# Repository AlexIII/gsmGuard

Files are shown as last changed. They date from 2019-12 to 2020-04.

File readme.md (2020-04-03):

# GsmGuard
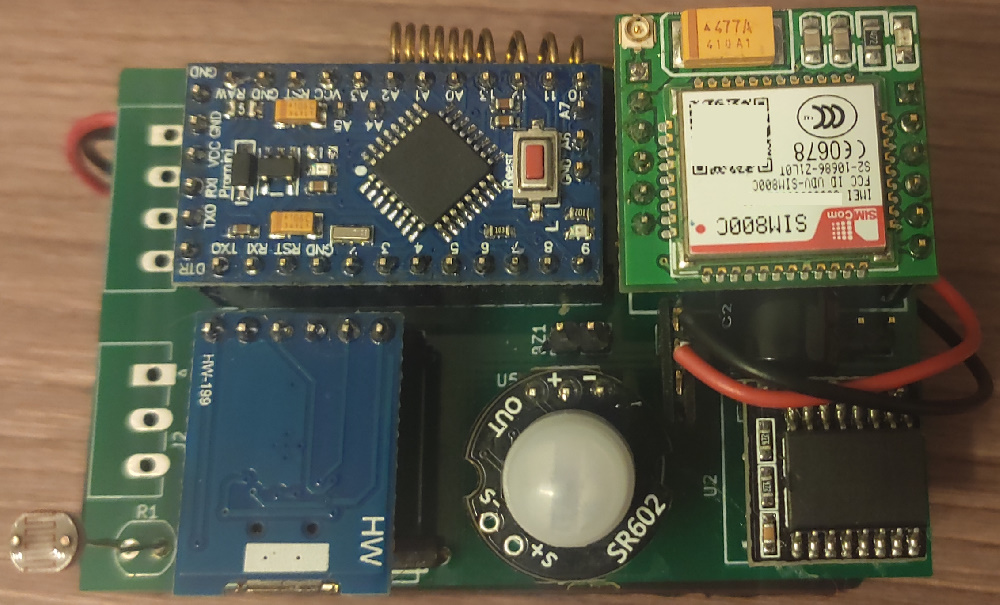
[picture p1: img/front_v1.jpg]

A compact multi-purpose all-in-one open source GSM alarm system.
Build on the base of Arduino Pro Mini and Arduino-compatible modules.

## Features
### Communication
The device sends an SMS on any alarm event and optionally a status report once a day.
Why SMS and not internet service? SMS stays most reliable means of mobile communication in cases of poor signal quality, requires less energy and works directly without relying on central server (which needs to be maintained by someone and may present a security  problem).

Example of an alarm SMS:
```
04.11.19 22:37
Movement detected
```
Example of a daily report SMS:
```
door: Closed [04.11.19 09:14] <-- date and time of last door open event
move: None [04.11.19 09:12] <-- date and time of last movement detection event
temp.: 28*C [min. 21*C, max. 28*C, mean 27*C] <-- current temperature and temperature statistics for the current day
light: 99% <-- current illumination level (0 to 100%)
bat.: 4.6v <-- current battery voltage
ext.1: 0 <-- current state of external sensor 1
ext.2: 0 <-- current state of external sensor 2
```

For every alarm event you can also enable a call to your phone or/and sound alarm.

### Sensors

- Door open sensor (magnetic reed switch)
- Illumination level sensor (photoresistor)
- Motion sensor (PIR sensor)
- Temperature sensor (built-in DS3231)

### Alarm events
- Open door
- Rapid illumination change
- Motion detection
- Too high or too low temperature
- Low battery voltage

### Power supply
Three AA batteries. Expected lifetime: 3 to 6 months.

### Configuration and logging
The device can be connected to a PC via USB for configuration.
Configuration program lets you set target phone number, time of daily SMS report, choose events that will be reported, a way of notification (SMS, call, sound alarm) and set time periods during which those events are being monitored. I.e. if you know that the room is being used during some hours in certain days of the week, you can disable the alarm for that period.
It also shows the last 70 events with date and time and a temperature plot for the last 31 days (one measurement every 2 hours).

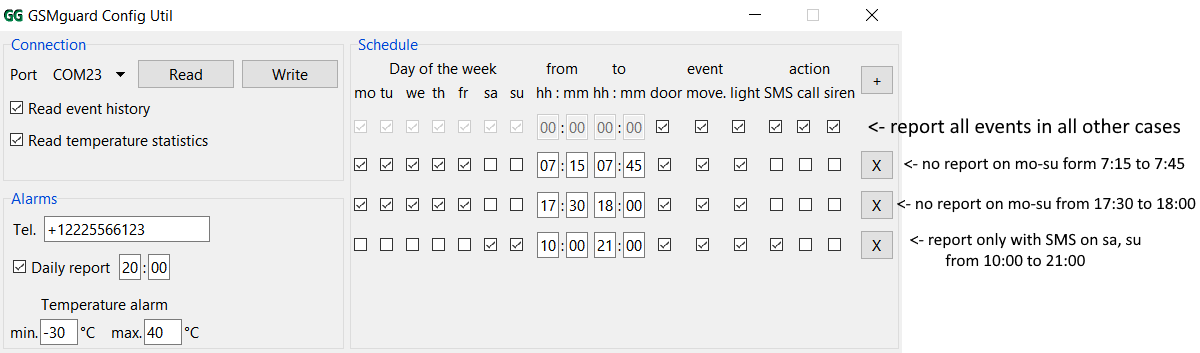
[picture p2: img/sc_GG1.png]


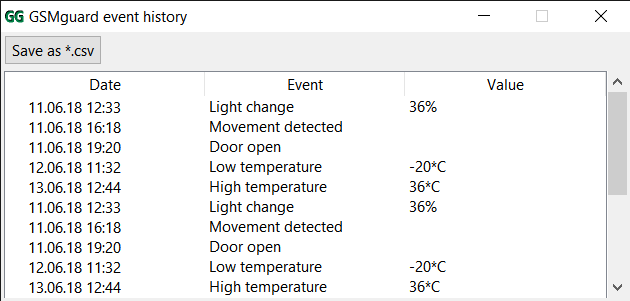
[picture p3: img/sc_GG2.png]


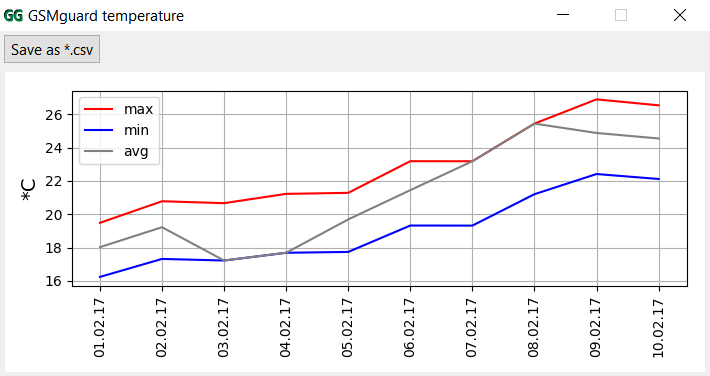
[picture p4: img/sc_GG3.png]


### Localization

Currently supported languages (SMS and configuration program for PC): English, Russian.

Date format: dd/mm/yy

Temperature units: degrees Celsius

## Assembling guide
### Hardware
#### List of components

List of Arduino modules you will need:

- Arduino Pro Mini 3.3v 8MHz (5v 16MHz is also acceptable, but requires different firmware) 

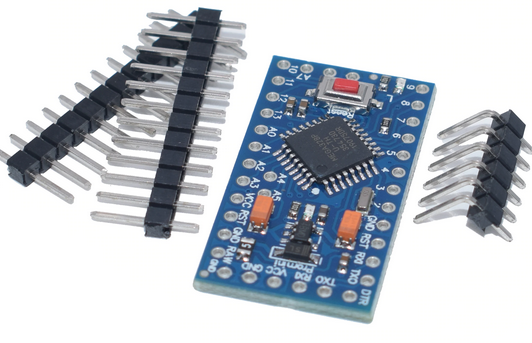
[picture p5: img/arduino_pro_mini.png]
  

-  MH-SR602 MINI Motion Sensor 

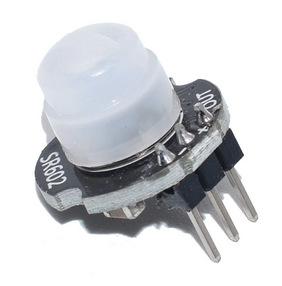
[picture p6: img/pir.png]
  

-  SIM800C GSM Module

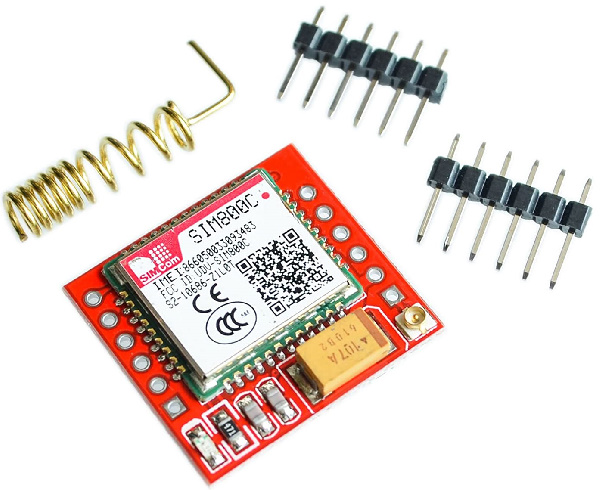
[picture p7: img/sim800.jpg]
  

-  CP2102 MICRO USB to UART TTL Module

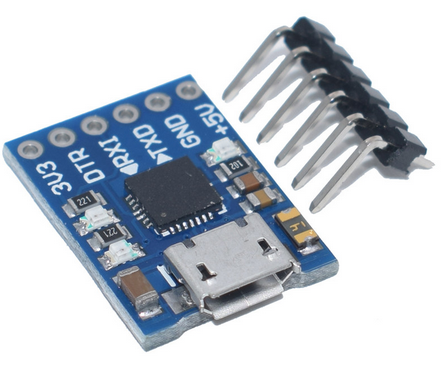
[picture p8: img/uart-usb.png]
  

-  DS3231 RTC Module For Raspberry Pi 

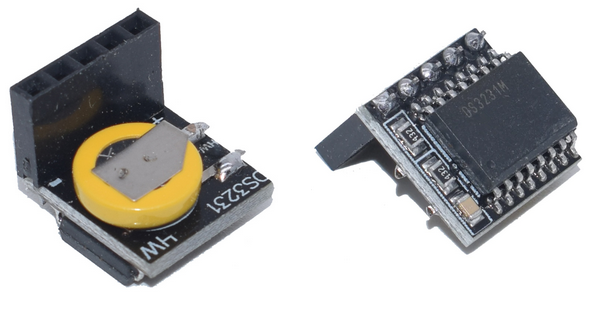
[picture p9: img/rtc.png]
  

Other components

- any >0.5A logic-level P-channel MOSFET in SOT-23

- reed switch

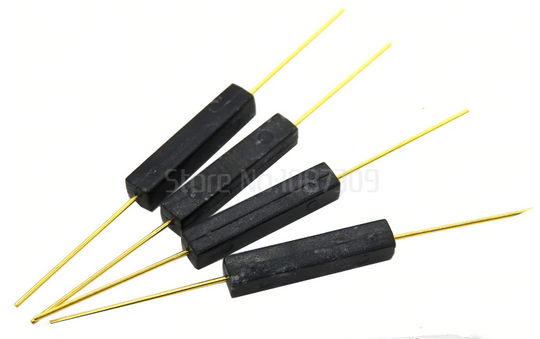
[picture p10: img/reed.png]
  

- buzzer 3 to 5v

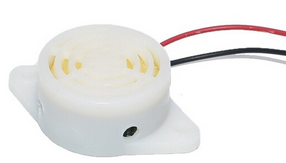
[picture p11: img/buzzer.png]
  

- electret microphone

- photoresistor

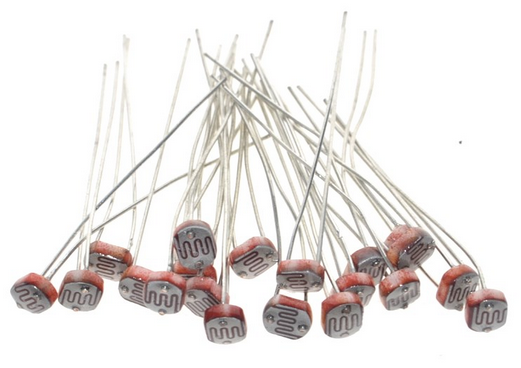
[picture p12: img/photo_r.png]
  

- resistors, capacitors 

The schematics:

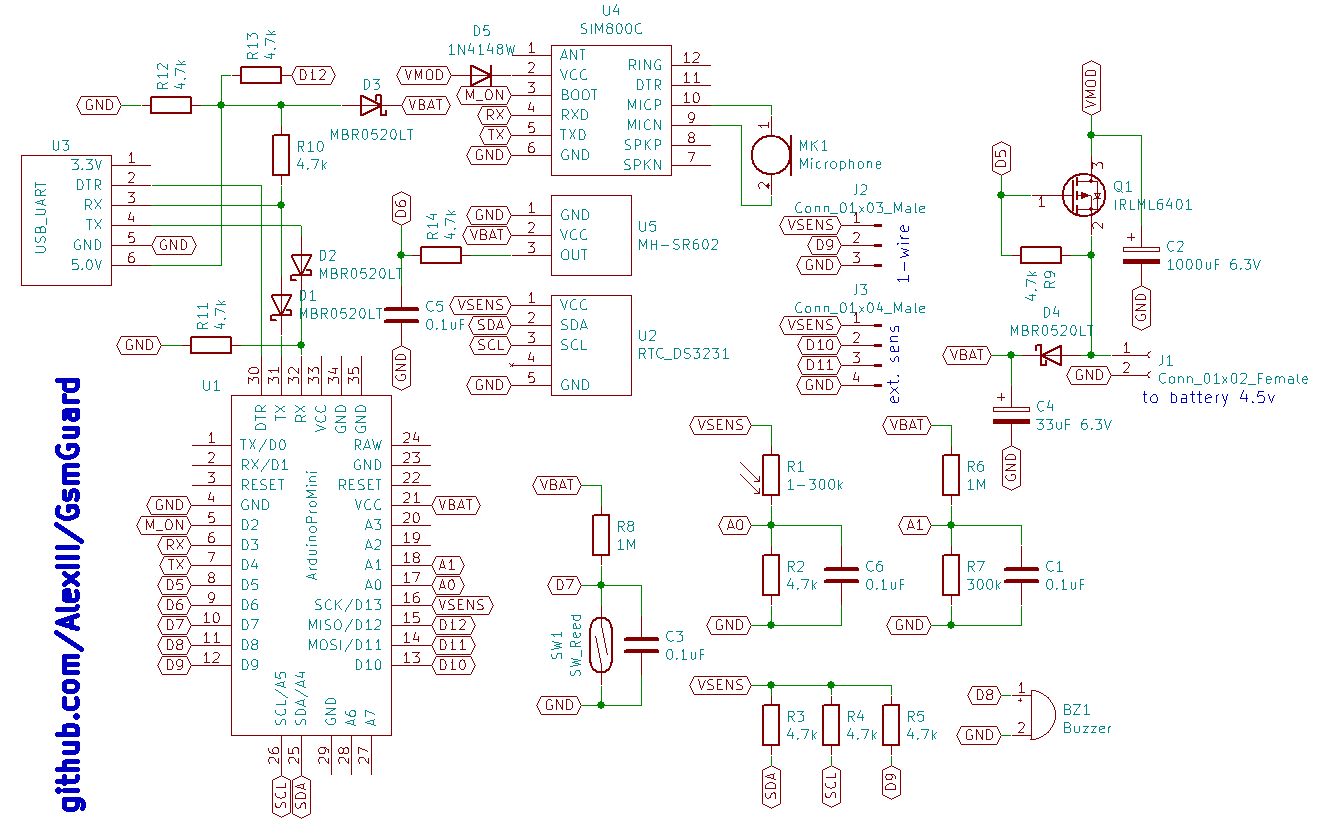
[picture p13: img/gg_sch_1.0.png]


#### Important Note
Remove power LED or the resistor that goes in series with it from the Arduino board. Otherwise it will drain the batteries in a matter of few days. It is better to remove voltage regulator IC from the Arduino too, as it's not being used but still draws a little bit of current.
#### Giving out PCBs
I have 9 leftover PCBs of the first iteration that I can send via mail (for free). It's a first version, so it has some errors which you will need to fix with a cutter and a few jump wires. If you interested write me to 

### Software

#### Flashing Arduino

You can upload precompiled `*.hex` firmware to Arduino via [xLoader](http://www.hobbytronics.co.uk/arduino-xloader). There's four firmware files available:

| hex file | description |
| --- | --- |
| gsmGuard-firmware-EN-8MHz.hex  | 8MHz arduino, english SMS  |
| gsmGuard-firmware-EN-16MHz.hex | 16MHz arduino, english SMS |
| gsmGuard-firmware-RU-8MHz.hex  | 8MHz arduino, russian SMS  |
| gsmGuard-firmware-RU-16MHz.hex | 16MHz arduino, russian SMS |

#### Running configuration program

- Windows 

  Run gsmGuardConf_v1.0.exe. It requires no installation, but the unpacking process is rather slow, it may take 10-20 seconds to run.

- Linux

  `~$ python2.7 gsmGuardConf.py`

## Usage notes
- The device pauses its normal operation when it's connected to USB.
- If the device failed to send an SMS, it will try again in 2 minutes, then again in 5, in 10, in 20, twice in 40 and then every 12 hours.
- After a successful call the device will hang-up in 3 minutes.
- The sound alarm will be on for 30 seconds.
- Door, movement and light change events are not monitored for 20 minutes after the last reported event.
- If the device's power was turned off for three hours, the temperature history gets erased.

## Known issues
It looks like PIR sensors perform badly in cold temperature. Mine starts losing stability (frequent false tripping) when ambient temperature drops below +5 Celsius.  I'm sure it havely depends on the particular model, though.

## Project files
- /config-util - PC configuration program. Python 2.7 + Tk + pyserial + matplotlib
- /gsmGuard-firmware - Arduino firmware. In order to successfully compile it, you need to manually install these libs:
  1. RTCLib from https://github.com/NeiroNx/RTCLib (clone the repo or use version ABOVE v1.5.8 if such release exists)
- /kicad-project - KiCAD schematics and board

## License

MIT License © github.com/AlexIII

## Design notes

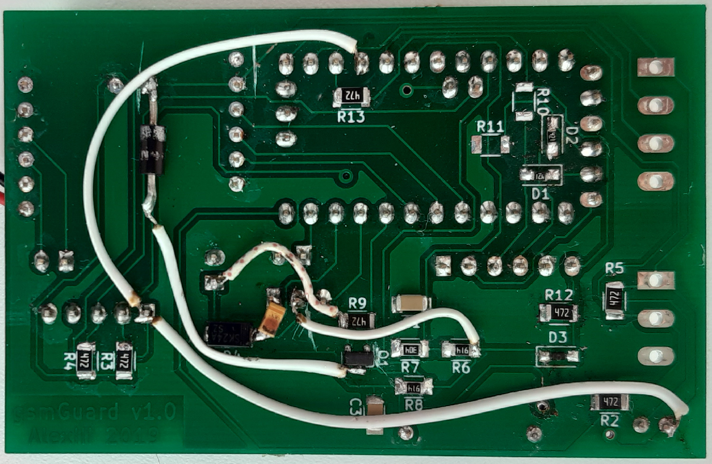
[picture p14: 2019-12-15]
img/back_v1.jpg

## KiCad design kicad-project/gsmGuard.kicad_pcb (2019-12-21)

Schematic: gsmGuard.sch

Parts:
BZ1: Buzzer; Pin_Header_Straight_1x02_Pitch2.54mm
C1, C3, C5, C6: 0.1uF; C_1206
C2: 1000uF 6.3V; CP_Radial_D8.0mm_P3.50mm
C4: 33uF 6.3V; CP_Tantalum_Case-C_EIA-6032-28_Reflow
D1, D2, D3, D4: MBR0520LT; D_SOD-123F
D5: 1N4148W; D_SOD-123F
J1: Conn_01x02_Female; Pin_Header_Straight_1x02_Pitch2.54mm
J2: Conn_01x03_Male; PhoenixContact_MC-G_03x3.81mm_Angled
J3: Conn_01x04_Male; PhoenixContact_MC-G_04x3.81mm_Angled
MK1: Microphone; Pin_Header_Straight_1x02_Pitch2.54mm
Q1: IRLML6401; SOT-23
R1: 1-300k; Resistor_LDR_4.9x4.2_RM2.54
R2, R3, R4, R5, R9, R12, R13, R14: 4.7k; R_1206
R6, R8: 1M; R_1206
R7: 300k; R_1206
R10, R11: 1k; R_1206
SW1: SW_Reed; reed-1
U1: ArduinoProMini; pro_mini
U2: RTC_DS3231; Pin_Header_Straight_1x05_Pitch2.54mm
U3: USB_UART; Pin_Header_Straight_1x06_Pitch2.54mm
U4: SIM800C
U5: MH-SR602; Pin_Header_Straight_1x03_Pitch2.54mm

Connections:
A0: C6.1, R1.2, R2.1, U1.17 (A0)
A1: C1.1, R6.2, R7.1, U1.18 (A1)
D5: Q1.1, R9.2, U1.8 (D5)
D6: C5.1, R14.1, U1.9 (D6)
D7: C3.1, R8.2, SW1.2, U1.10 (D7)
D8: BZ1.1, U1.11 (D8)
D9: J2.2, R5.2, U1.12 (D9)
D10: J3.2, U1.13 (D10)
D11: J3.3, U1.14 (MOSI/D11)
D12: R13.2, U1.15 (MISO/D12)
GND: BZ1.2, C1.2, C2.2, C3.2, C4.2, C5.2, C6.2, J1.2, J2.3, J3.4, R2.2, R7.2, R11.1, R12.1, SW1.1, U1.4 (GND), U2.5 (GND), U3.5 (GND), U4.6 (GND), U5.1 (GND)
M_ON: U1.5 (D2), U4.3 (BOOT)
unnamed: D1.1, U1.31 (TX)
unnamed: D1.2, R10.2, U3.3 (RX)
unnamed: D2.1, R11.2, U1.32 (RX)
unnamed: D2.2, U3.4 (TX)
unnamed: D3.2, R10.1, R12.2, R13.1, U3.6 (5.0V)
unnamed: D4.2, J1.1, Q1.2, R9.1
unnamed: D5.1, U4.2 (VCC)
unnamed: MK1.1, U4.10 (MICP)
unnamed: MK1.2, U4.9 (MICN)
unnamed: R14.2, U5.3 (OUT)
unnamed: U1.30 (DTR), U3.2 (DTR)
RX: U1.6 (D3), U4.4 (RXD)
SCL: R4.2, U1.26 (SCL/A5), U2.3 (SCL)
SDA: R3.2, U1.25 (SDA/A4), U2.2 (SDA)
TX: U1.7 (D4), U4.5 (TXD)
VBAT: C4.1, D3.1, D4.1, R6.1, R8.1, U1.21 (VCC), U5.2 (VCC)
VMOD: C2.1, D5.2, Q1.3
VSENS: J2.1, J3.1, R1.1, R3.1, R4.1, R5.1, U1.16 (SCK/D13), U2.1 (VCC)

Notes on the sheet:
to battery 4.5v
1-wire
ext. sens
github.com/AlexIII/GsmGuard

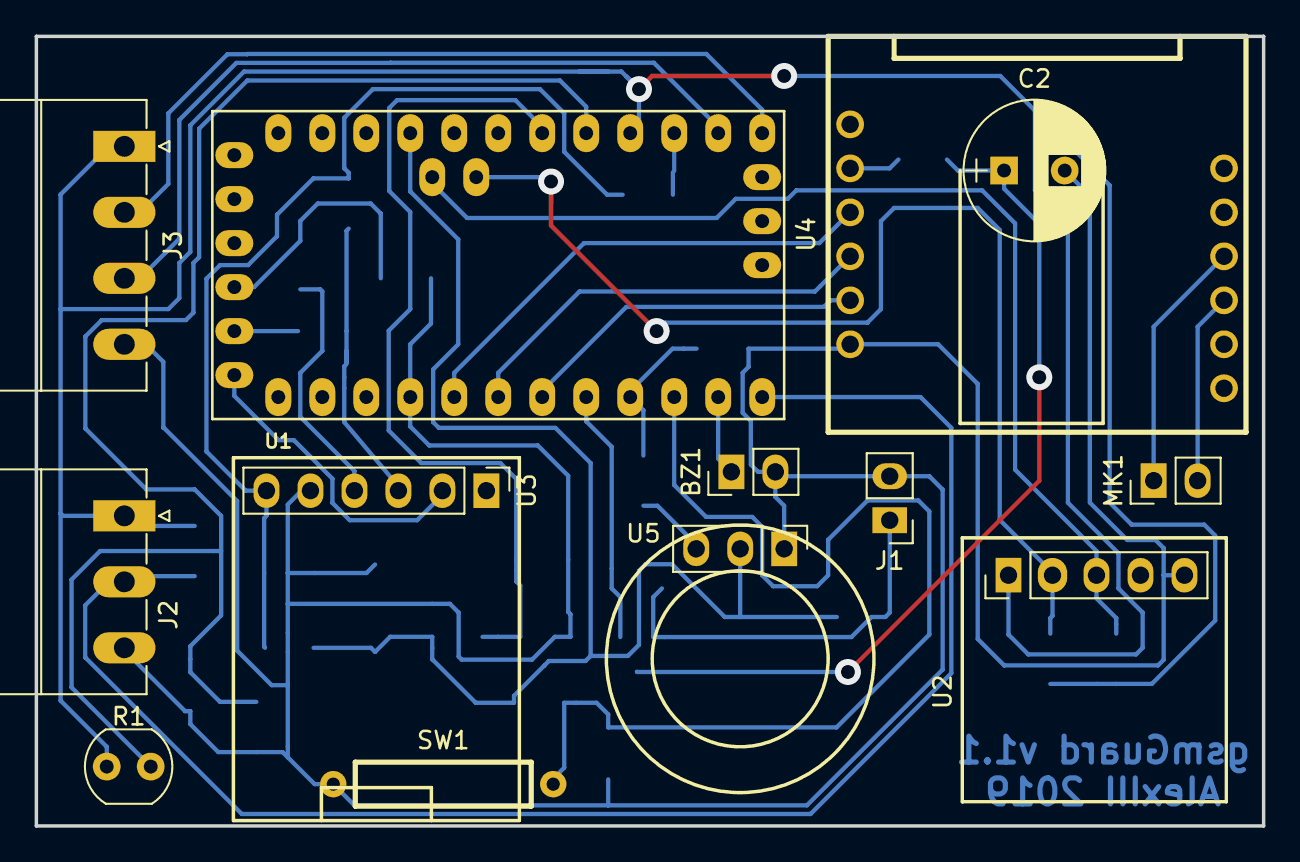
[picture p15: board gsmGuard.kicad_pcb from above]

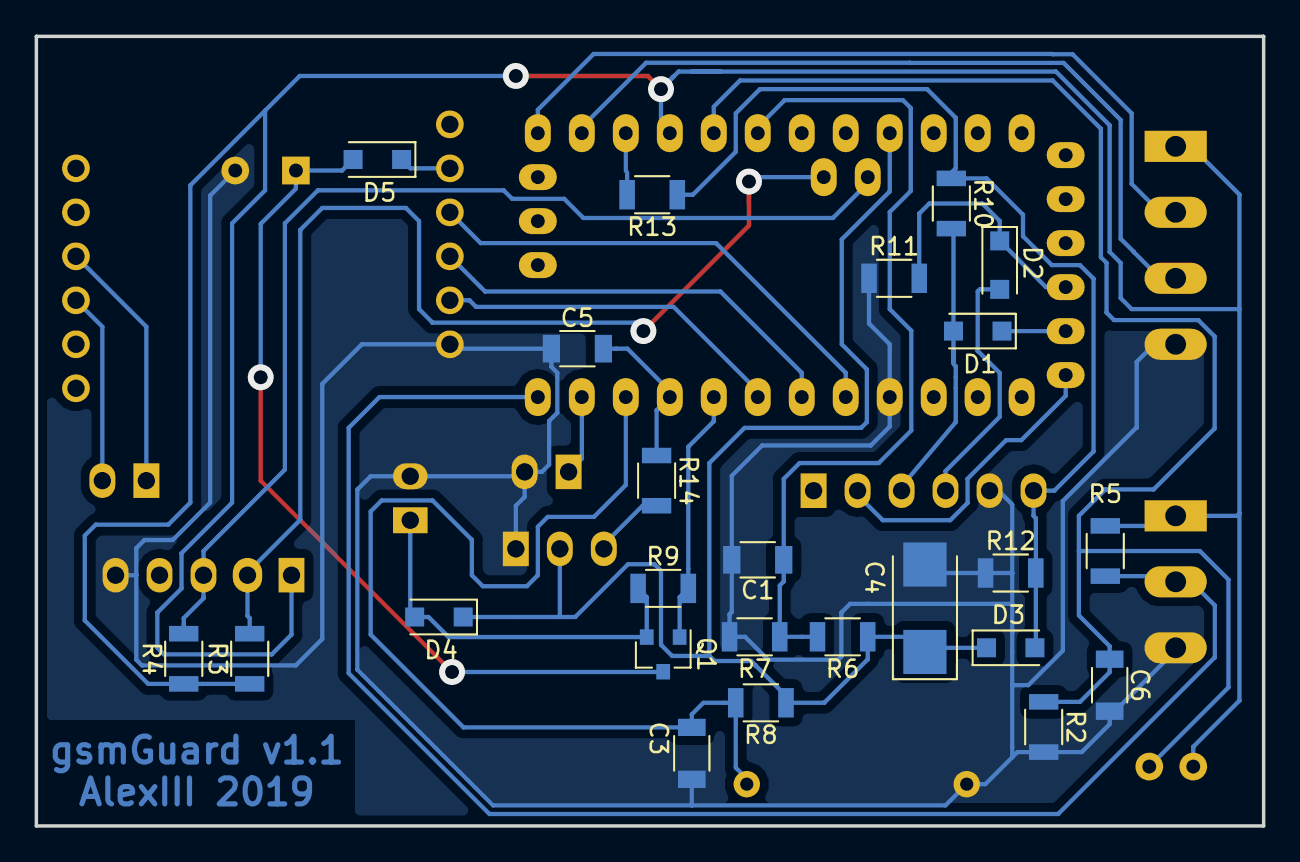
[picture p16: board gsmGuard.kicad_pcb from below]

Board: 2 copper layers, 70.9 x 45.6 mm, 37 parts (24 on the bottom side), 30 nets.

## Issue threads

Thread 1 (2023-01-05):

Ошибка компиляции

Metr-FM, 2023-01-05:
Arduino: 1.8.19 (Windows 7), Плата:"Arduino Nano, ATmega168"
При комплекции скетча выдает ошибку.

gsmGuard-firmware:39:4: error: #error "F_CPU is not 8 MHz! Select board with 8MHz clock even if you actually use 16MHz. (in which case also #define F_CPU_16MHZ at the beginning of *.ino file)"

   #error "F_CPU is not 8 MHz! Select board with 8MHz clock even if you actually use 16MHz. (in which case also #define F_CPU_16MHZ at the beginning of *.ino file)"

    ^~~~~

exit status 1

#error "F_CPU is not 8 MHz! Select board with 8MHz clock even if you actually use 16MHz. (in which case also #define F_CPU_16MHZ at the beginning of *.ino file)"

AlexIII, 2023-01-05:
Следуйте инструкциям, которые даны в тексте ошибки: раскомментируйте `#define F_CPU_16MHZ`  и выберете плату 8MHz в настройках проекта.

Metr-FM, 2023-01-05:
раскомментируйте #define F_CPU_16MHZ
и выбрал в настройках программы (через Инструменты) Arduino Nano, ATmega168.
Результат такой же. Что делаю не так?

Arduino: 1.8.19 (Windows 7), Плата:"Arduino Nano, ATmega168"

gsmGuard-firmware:39:4: error: #error "F_CPU is not 8 MHz! Select board with 8MHz clock even if you actually use 16MHz. (in which case also #define F_CPU_16MHZ at the beginning of *.ino file)"

   #error "F_CPU is not 8 MHz! Select board with 8MHz clock even if you actually use 16MHz. (in which case also #define F_CPU_16MHZ at the beginning of *.ino file)"

    ^~~~~

exit status 1

#error "F_CPU is not 8 MHz! Select board with 8MHz clock even if you actually use 16MHz. (in which case also #define F_CPU_16MHZ at the beginning of *.ino file)"

Metr-FM, 2023-01-05:
Исправил. вышла новая ошибка.

Arduino: 1.8.19 (Windows 7), Плата:"Arduino Pro or Pro Mini, ATmega328P (3.3V, 8 MHz)"

In file included from D:\Arduino Projects\gsmGuard-firmware\Hardware.h:13:0,

                 from D:\Arduino Projects\gsmGuard-firmware\Status.h:10,

                 from D:\Arduino Projects\gsmGuard-firmware\gsmGuard-firmware.ino:34:

D:\Arduino Projects\gsmGuard-firmware\TempHistory.h: In member function 'void TempHistory::dumpCSV(Stream&, char) const':

D:\Arduino Projects\gsmGuard-firmware\TempHistory.h:48:22: warning: comparison between signed and unsigned integer expressions [-Wsign-compare]

     for(int i = 0; i < samples.size(); ++i) {

                    ~~^~~~~~~~~~~~~~~~

In file included from D:\Arduino Projects\gsmGuard-firmware\Status.h:10:0,

                 from D:\Arduino Projects\gsmGuard-firmware\gsmGuard-firmware.ino:34:

D:\Arduino Projects\gsmGuard-firmware\Hardware.h: In static member function 'static Hardware::Sensors Hardware::sensors()':

D:\Arduino Projects\gsmGuard-firmware\Hardware.h:88:59: warning: comparison between signed and unsigned integer expressions [-Wsign-compare]

     if((cur - tempHistory.lastEntryTime()).totalseconds() > 2UL*3600UL) //2 hr.

        ~~~~~~~~~~~~~~~~~~~~~~~~~~~~~~~~~~~~~~~~~~~~~~~~~~~^~~~~~~~~~~~

In file included from D:\Arduino Projects\gsmGuard-firmware\Events.h:8:0,

                 from D:\Arduino Projects\gsmGuard-firmware\Status.h:11,

                 from D:\Arduino Projects\gsmGuard-firmware\gsmGuard-firmware.ino:34:

D:\Arduino Projects\gsmGuard-firmware\Event.h: In member function 'const __FlashStringHelper* Event::name() const':

D:\Arduino Projects\gsmGuard-firmware\Event.h:68:11: warning: enumeration value 'NO_EVENT' not handled in switch [-Wswitch]

     switch(n) {

           ^

In file included from D:\Arduino Projects\gsmGuard-firmware\Status.h:12:0,

                 from D:\Arduino Projects\gsmGuard-firmware\gsmGuard-firmware.ino:34:

D:\Arduino Projects\gsmGuard-firmware\Config.h: In member function 'bool Config::SchEntry::isActive() const':

Config.h:56:31: error: 'const class DateTime' has no member named 'dayOfTheWeek'; did you mean 'dayOfWeek'?

       const uint8_t dw = (now.dayOfTheWeek()+6)%7;

                               ^~~~~~~~~~~~

                               dayOfWeek

In file included from D:\Arduino Projects\gsmGuard-firmware\gsmGuard-firmware.ino:34:0:

D:\Arduino Projects\gsmGuard-firmware\Status.h: In member function 'void Status::upd()':

D:\Arduino Projects\gsmGuard-firmware\Status.h:84:58: warning: comparison between signed and unsigned integer expressions [-Wsign-compare]

         if((Hardware::now() - prv.time()).totalseconds() > timeout)

            ~~~~~~~~~~~~~~~~~~~~~~~~~~~~~~~~~~~~~~~~~~~~~~^~~~~~~~~

D:\Arduino Projects\gsmGuard-firmware\gsmGuard-firmware.ino: In function 'ConfigAction getConfigStr(Stream&, char*, size_t, bool)':

D:\Arduino Projects\gsmGuard-firmware\gsmGuard-firmware.ino:73:10: warning: comparison between signed and unsigned integer expressions [-Wsign-compare]

     if(r >= confBuffSz-1) {

        ~~^~~~~~~~~~~~~~~

exit status 1

'const class DateTime' has no member named 'dayOfTheWeek'; did you mean 'dayOfWeek'?

Metr-FM, 2023-01-05:
Обновил все библиотеки как в описании по версии, компиляция прошла успешно, спасибо Александр!

Начал разбираться по схемотехнике и назначению пинов из скетча.
Верно ли определил что за  что отвечает? и за что отвечают другие пины, где я не прописал их назначение

#define LIGHT_PIN A0        //датчик освещенности
#define TEMP_PIN 9          //датчик температуры 1-wire  ?
#define BAT_PIN A1          //контроль Uакб
#define DOOR_PIN 7          //герконовый датчик на дверь
#define PIR_PIN 6           //датчик движения
#define EXT1_PIN 10
#define EXT2_PIN 11
#define BUZZER_PIN 8        //звуковая сирена
#define POWER_PIN 13        //
#define USB_POWER_DETECT 12 // датчик подключени USB

По схемотехнике вопросы не совсем понятно за что отвечают каскады. подскажите пожалуйста:
1) R3, R4, R5
2) чем управляет мосфет транзистор Q1?
3) разъемы J2 и J3 это для доработки самим или как.
4) для чего нужны ext1, ext2 это на  J3?
5) Обязательно ли нужны диоды шоттки D1, D2, D3, D4?
6) Зачем для GSM модуля микрофон МК1, Он может передавать при звонке звуки с гаража?
7) У GSM модуля SIM800С где-то видел ставят делитель напряжения на RX или на TX, здесь видимо не требуется так как напряжения питания 4,5В? И еще для понижения этого напряжения диод D5 стоит.
8) есть ли разница если поставить вместо SIM800С, аналогичный но SIM800L он вроде как на пониженное энергопотребления расчитанный.

AlexIII, 2023-01-06:
Посмотрите [схему](https://github.com/AlexIII/gsmGuard/blob/master/img/gg_sch_1.0.png)

Я уже не помню что-там за что отвечает. Все делалось для уменьшения энергопотребления и утечек тока.

Metr-FM, 2023-01-06:
Хорошо понял Александр.

А как запустить программу для настройки устройства?
В статье написано:
Настройка устройства, считывание логов событий и построение месячного графика температуры происходит с помощью утилиты (Python 2.7 + Tk + pyserial + matplotli).
То что в скобочках ничего не говорит для меня, Python 2.7 это видимо программа с версией, а остальное что такое?

Запуск любого файла в папке config-util не дает результата, что необходимо сделать чтобы запустить программу?

AlexIII, 2023-01-06:
Используйте собранный exe, если не хотите разбираться как запускать из исходников
https://github.com/AlexIII/gsmGuard/releases/tag/v1.3

Metr-FM, 2023-01-06:
Запустил собранный exe.
Выдает что нет ответа от устройства.

Metr-FM, 2023-01-06:
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

Metr-FM, 2023-01-06:
Залил прошивку hex файл gsmGuard-firmware-v1.3-RU-16MHz через XLoader, все прошло успешно.  Но связи с программой нет.

AlexIII, 2023-01-06:
Много причин может быть. Отлаживать вам придется самостоятельно. Откройте терминал arduino 250000 bod, там должно появиться сообщение "USB connection detected. Awaiting config." Пока не появится, с программой связи не будет. На D12 должно быть +VCC чтобы войти в режим приема команд.

Metr-FM, 2023-01-06:
Тогда понятно, я пока пытался только Ардуино с компьютером через программу состыковать без остальной схемотехники. В одном документе прочел что у вас еще есть изготовленная печатная плата, можно ли у Вас ее приобрести и как?

AlexIII, 2023-01-07:
К сожалению, плат нет

Metr-FM, 2023-01-07:
Понял, Александр. Буду собирать схему на макетной плате. Результаты после отпишусь.

Closed 2023-01-14.

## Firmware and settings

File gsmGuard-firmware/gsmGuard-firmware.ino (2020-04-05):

/*
 * GsmGuard v1.0
 * author: github.com/AlexIII
 * e-mail: endoftheworld@bk.ru
 * license: MIT
 */

/*
Libraries:
https://github.com/vshymanskyy/TinyGSM (v0.10.1)
https://github.com/Densaugeo/base64_arduino (v1.1.1)
https://github.com/NeiroNx/RTCLib/releases (v1.5.8 - install manually, as of now this version is not available in the Library Manager)
https://github.com/AlexIII/EEvar (v0.2.0)

Board: Arduino Nano / Pro / pro mini - 8MHz
*/ 

/* Select clock */
#define F_CPU_8MHZ
//#define F_CPU_16MHZ

/* Select locale */
//#define LOCAL_RU
#define LOCAL_EN

#define DEBUG_BAUDRATE 250000
#define AT_BAUDRATE 19200

#include <avr/sleep.h>
#define SerialMon Serial
#define TINY_GSM_DEBUG SerialMon
#include <SoftwareSerial.h>
#include "Reporter.h"
#include "Status.h"
#include "Scheduler.h"
#include "Config.h"

#if F_CPU != 8000000
  #error "F_CPU is not 8 MHz! Select board with 8MHz clock even if you actually use 16MHz. (in which case also #define F_CPU_16MHZ at the beginning of *.ino file)"
#endif

ConfigSerial config;
Status status(config);
SoftwareSerial SerialAT(4, 3); // RX, TX
Reporter reporter(SerialAT, config.phoneNumber);
Scheduler scheduler(config, status, reporter);

enum ConfigAction : uint8_t {
  NONE,
  CONFIG_SET,
  CONFIG_REQ,
  EVENTS_REQ,
  TEMP_REQ
};

class ExposedStream : public Stream {
  friend ConfigAction getConfigStr(Stream &stream, char* confBuff, const size_t confBuffSz, const bool wait);
};

ConfigAction getConfigStr(Stream &stream, char* confBuff, const size_t confBuffSz, const bool wait = true) {
  if(!wait && !stream.available()) return NONE;
  ExposedStream::MultiTarget targets[] = {
    {"\nCONFIG_V1: ", 12, 0},
    {"\nCONFIG_REQ",  11, 0},
    {"\nEVENTS_REQ",  11, 0},
    {"\nTEMP_REQ",     9, 0}
  };
  const int res = static_cast<ExposedStream&>(stream).findMulti(targets, 4) + 1;
  if(!res) return NONE;
  if(res == CONFIG_SET) {
    const int r = stream.readBytesUntil('\n', confBuff, confBuffSz-1);
    if(!r) return NONE;
    if(r >= confBuffSz-1) {
      DBG(F("Error: Config buffer overflow."));
      return NONE;
    }
    confBuff[r] = 0; //add string terminator
  }
  while(stream.read() != -1); //flush buffer, we've got our answer
  return ConfigAction(res);
}

void csvBegin() {
  SerialMon.println(F("\r\n----CSV BEGIN----"));
}
void csvEnd() {
  SerialMon.println(F("----CSV END----"));
}

void dumpEventHistCSV() {
  csvBegin();
  status.events.dumpCSV(SerialMon);
  csvEnd();
}

void dumpTempCSV() {
  csvBegin();
  tempHistory.dumpCSV(SerialMon);
  csvEnd();
}

bool receiveCommand(const bool wait = true) {
    char confBuffer[(8*sizeof(config))/6 + 20];
    const ConfigAction act = getConfigStr(SerialMon, confBuffer, sizeof(confBuffer), wait);
    
    if(act) {
      DBG(F("REQ RECEIVED"));
      if(act == CONFIG_SET) {
        DBG(F("Config string received:"), confBuffer);
        if(config.formBASE64(confBuffer)) {
          DBG(F("New config successfully applyed!"));
          SerialMon.println(F("\r\nSET_OK"));
        } else {
          DBG(F("Error: wrong config."));
          SerialMon.println(F("\r\nSET_ERR"));
        }
        return true;
      } else if(act == CONFIG_REQ) {
        DBG(F("Config request"));
        SerialMon.print(F("\r\nCONFIG_V1: "));
        config.toBASE64(SerialMon);
        SerialMon.println();
        return true;
      } else if(act == EVENTS_REQ) {
        DBG(F("Event history request"));
        dumpEventHistCSV();
        return true;
      } else if(act == TEMP_REQ) {
        DBG(F("Temperature history request"));
        dumpTempCSV();
        return true;
      }
    }
    return false;
}

void setup() {
  /* clock */
#ifndef F_CPU_8MHZ
  CLKPR = (1<<CLKPCE);
  CLKPR = (1<<CLKPS0); //clock prescale = 2
#endif
  /* power saving */
  ACSR = (1<<ACD); //disable ACOMP
  
  SerialMon.begin(DEBUG_BAUDRATE);
  SerialMon.setTimeout(2000);
  delay(50);
  SerialAT.begin(AT_BAUDRATE);
  
  Hardware::init();
  delay(300);
  status.init();
  DBG(F("System inited."));

  
  
  //reset history
  /*
  tempHistory.reset();
  status.events.reset();
  */

  /*
  tempHistory.update(-10, Hardware::now());
  tempHistory.update(-6, Hardware::now());
  tempHistory.update(-2, Hardware::now());
  tempHistory.update(10, Hardware::now());
  tempHistory.update(5, Hardware::now());
  tempHistory.update(0, Hardware::now());
  */

  /*
  //PIR test
  digitalWrite(LED_BUILTIN, HIGH);
  Hardware::pwrOn();
  while(1) {
    DBG(F("PIR:"), digitalRead(PIR_PIN));
    delay(200);
  }
  */

  char t[] = "DD.MM.YY hh:mm:ss";
  DBG(F("Time:"), Hardware::now().format(t));
  DBG(F("Free EEPROM bytes:"), EEPROMallocator::free());

  if(Hardware::isExtPower() || receiveCommand(true)) { //We're being configurated, so 
    if(Hardware::isExtPower()) DBG(F("USB connection detected. Awaiting config."));
    status.events.clearActions(); //no need to report old events,
    while(1) {
      receiveCommand(); //no need to run the main program.
    }
  }
  
  if(!config.chkCRC()) { //broken config
    status.events.reset(); //reset memory
    tempHistory.reset();
    SerialMon.println(F("Broken config.\r\nSystem halted."));
    while(1); 
  }

  sleep_init();
}

ISR(WDT_vect) {}
void sleep_init() {
  set_sleep_mode(SLEEP_MODE_PWR_DOWN);
  sleep_enable();
  PCICR |= (1<<PCIE2);
  PCMSK2 |= (1<<PCINT23) | (1<<PCINT22);
  pinMode(LED_BUILTIN, OUTPUT);
  digitalWrite(LED_BUILTIN, HIGH);
}

void sleep() {
  digitalWrite(LED_BUILTIN, LOW);
  SerialMon.flush();
  SerialMon.end();
  SerialAT.flush();
  SerialAT.end();
  Hardware::pwrOff();

  const uint8_t DB = DDRB, DC = DDRC, DD = DDRD;
  DDRB = 0, DDRC = 0, DDRD = 0;
  const uint8_t PB = PORTB, PC = PORTC, PD = PORTD;
  PORTB = 0, PORTC = 0, PORTD = 0;
  
  asm volatile("wdr");
  WDTCSR |= (1<<WDCE)|(1<<WDE);
  WDTCSR = (1<<WDIE)|(1<<WDP2)|(1<<WDP3)|(1<<WDP0);
  sleep_cpu();
  WDTCSR |= (1<<WDCE)|(1<<WDE);
  WDTCSR = 0;

  PORTB = PB, PORTC = PC, PORTD = PD;
  DDRB = DB, DDRC = DC, DDRD = DD;

  digitalWrite(LED_BUILTIN, HIGH);
  Hardware::pwrOn();
  SerialMon.begin(DEBUG_BAUDRATE);
  SerialAT.begin(AT_BAUDRATE);
}

void loop() {
  const auto s = millis();
  status.upd();
  DBG(F("Unreported queue size:"), status.events.unreportedCount(Event::ANY));
  char t[] = "DD.MM.YY hh:mm:ss";
  DBG(F("Time:"), Hardware::now().format(t));
  DBG(F("Status:"));
  status.print(TINY_GSM_DEBUG);
  TINY_GSM_DEBUG.println();
  scheduler.poll();
  DBG(F("Cycle time, ms.:"), millis()-s);
  
  sleep();
}

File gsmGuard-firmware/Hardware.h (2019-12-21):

/*
 * GsmGuard v1.0
 * author: github.com/AlexIII
 * e-mail: endoftheworld@bk.ru
 * license: MIT
 */

#ifndef _HARDWARE_H_
#define _HARDWARE_H_

#include <RTClib.h>
#include <Wire.h>
#include "TempHistory.h"

#define PIR_RELAX_TIME_MIN 20

#define LIGHT_PIN A0
#define TEMP_PIN 9
#define BAT_PIN A1
#define DOOR_PIN 7
#define PIR_PIN 6
#define EXT1_PIN 10
#define EXT2_PIN 11
#define BUZZER_PIN 8
#define POWER_PIN 13
#define USB_POWER_DETECT 12

TempHistory tempHistory(2UL*3600UL);
DS3231 rtc;

class Hardware {
  Hardware();
public:
  struct TempStat {
    int8_t min;
    int8_t max;
    int8_t avg;
  };

  struct Sensors {
    uint8_t light;  //%
    int8_t temp;    //deg. Celsius
    uint8_t bat;    // bat/10 = volts
    bool doorIsOpen;
    bool move;
    bool ext1;
    bool ext2;
  };

  static TempStat& tempStat() {
    static TempStat t{-127, -127, -127};
    return t;
  }
  static void init() {
    pinMode(USB_POWER_DETECT, INPUT);
    analogReference(INTERNAL);
    pinMode(DOOR_PIN, INPUT);
    pinMode(PIR_PIN, INPUT);
    pinMode(EXT1_PIN, INPUT);
    pinMode(EXT2_PIN, INPUT);
    pinMode(EXT2_PIN, INPUT);
    digitalWrite(EXT1_PIN, HIGH);
    digitalWrite(EXT2_PIN, HIGH);
    pinMode(BUZZER_PIN, OUTPUT);
    beep(false);
    pwrOn();
    if(!rtc.isrunning()) rtc.adjust(DateTime(F(__DATE__), F(__TIME__)));
  }
  static bool isExtPower() {
    return digitalRead(USB_POWER_DETECT);
  }
  static void pwrOn() {
    digitalWrite(POWER_PIN, HIGH);
    pinMode(POWER_PIN, OUTPUT);
    delay(1);
    rtc.begin();
  }
  static void pwrOff() {
    Wire.end();
    digitalWrite(POWER_PIN, LOW);
    pinMode(POWER_PIN, INPUT);
  }
  static Sensors sensors() {
    const DateTime cur = now();
    const int8_t t = temp(cur);
    updTempStat(t, cur);

    if((cur - tempHistory.lastEntryTime()).totalseconds() > 2UL*3600UL) //2 hr.
      tempHistory.update(t, cur);

    return {
      light(),
      t,
      bat(),
      digitalRead(DOOR_PIN),
      pir(cur),
      !digitalRead(EXT1_PIN),
      !digitalRead(EXT2_PIN)
    };
  }
  static DateTime now() {
    return rtc.now();
  }
  static void setTime(const char* date) { //"DD.MM.YYYY hh:mm:ss"
    rtc.adjust(DateTime(date, date+11));
  }
  static void beep(const bool on) {
    if(on) {
      //pinMode(BUZZER_PIN, OUTPUT);
      digitalWrite(BUZZER_PIN, HIGH);
    } else {
      //pinMode(BUZZER_PIN, INPUT);
      digitalWrite(BUZZER_PIN, LOW);
    }
  }
  static void beep(const int sec) {
    const uint32_t end = millis() + sec*1000UL;
    while(end > millis()) {
      beep(true);
      delay(200);
      beep(false);
      delay(50);
    }
  }

  static void updButVoltage() {
    bat() = analogRead(BAT_PIN) / 21U;
  }
private:
  static int8_t temp(const DateTime &cur) {
    return round(rtc.getTemp());
  }
  static uint8_t light() {
    return (uint32_t(analogRead(LIGHT_PIN))*100)/1024UL;
  }
  static uint8_t& bat() {
    static uint8_t val = 0;
    return val;
  }
  static bool pir(const DateTime &curTime) {
#ifdef PIR_RELAX_TIME_MIN
    static DateTime lastOn;
    bool cur = digitalRead(PIR_PIN);
    if(cur) {
      if((curTime - lastOn).totalseconds() < PIR_RELAX_TIME_MIN*60)
        cur = false;
      lastOn = curTime;
    }
    return cur;
#else
    return digitalRead(PIR_PIN);
#endif
  }
  
  static void updTempStat(const int8_t t, const DateTime &cur) {
    //for avg
    static uint16_t cnt = 1; //5min intervals
    static DateTime last;
    
    //daily reset
    TempStat &ts = tempStat();
    static uint8_t statTempResetDay = 0;
    if(statTempResetDay != cur.day()) {
      statTempResetDay = cur.day();
      //if(cnt > 1) tempHistory.update(ts, cur);
      resetTempStat(t);
      cnt = 1;
      last = cur;
      return;
    }

    //update
    if(ts.min > t) ts.min = t;
    if(ts.max < t) ts.max = t;
    if((cur - last).totalseconds() > 300) {
      last = cur;
      ts.avg = (int32_t(ts.avg)*cnt + t) / (cnt+1);
      ++cnt;
    }
  }
  static void resetTempStat(const int8_t t) {
    tempStat().min = tempStat().max = tempStat().avg = t;
  }
};

#endif

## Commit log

2019-12-21 improve PIR sensor stability
    [Hardware.h]
2019-12-21 fix resistor values
    [gsmGuard.kicad_pcb, gsmGuard.sch]
2019-12-21 use EEvar library, fix 16MHz boards support
    [gsmGuard-firmware.ino]
2019-12-21 remove 2 of 4 hacks of Arduino IDE needed for compilation
2019-12-22 fix readme: no Arduino IDE tweaks are needed
2020-01-02 config: enable/disable temperature alarm
2020-04-02 update arduino libs
2020-04-03 config util bugfix, fix readme
    [Connector.py, gsmGuard-firmware.ino]
2020-04-05 firmware stack owerflow fix
    [Connector.py, Local.h, Reporter.h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]
